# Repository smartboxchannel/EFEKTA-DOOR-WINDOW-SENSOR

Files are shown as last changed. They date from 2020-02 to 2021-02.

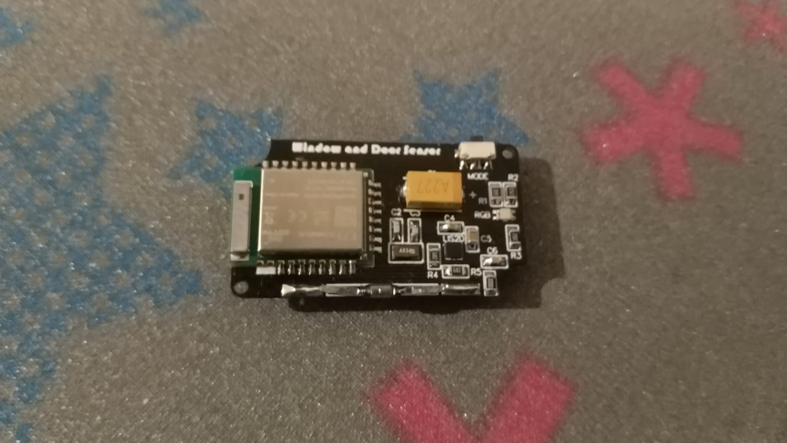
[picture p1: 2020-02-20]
IMAGES/3.jpeg

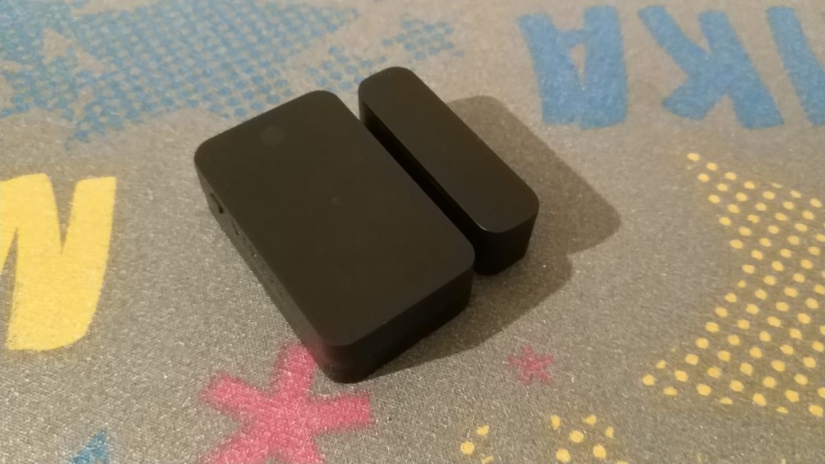
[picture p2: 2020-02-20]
IMAGES/1.jpeg

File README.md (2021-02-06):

# EFEKTA-DOOR-WINDOW-SENSOR

## Reed Switch, LIS2DW12, DRV5032FB

### (MC50SFA) nRF52811, nRF52810, nRF52832, (E73 2G4M08S1C) nRF52840

#### Don't donate to me, it doesn't work in this world: https://paypal.me/efektalab , just buy:

Video: https://youtu.be/4p1JGMze4s0

More info at http://efektalab.com/dws52 (still not working)

---

### Components (see also BOM.CSV):
#### (MC50SFA) nRF52811, nRF52810, nRF52832

1. (MC50SFA) nRF52811, nRF52810, nRF52832 (U1) - https://ali.ski/W6ErD

2. lis2dw12 (U2) - optional - https://ali.ski/h80NdJ

3. a. Reed Switch 2х14 (U3) - https://ali.ski/Uyxms

OR

3. b. Reed Switch 1.8х10 (U3) - https://ali.ski/WHlYoO

OR

3. c. Reed Switch 1.8х10 (U3) - https://ali.ski/4hPWm2

4. CR2032 Holder (U4) - https://ali.ski/9lSL8n

5. Micro Switch 2*4*3,5mm (U5,U6) - https://ali.ski/Q_WYyZ

6. DRV5032FB (U7,U8) - optional

7. RGB LED | SMD 0805 | RGBL | RGB LED - https://ali.ski/Dhf3R

8. 0603 SMD 1/8W chip resistor 3.6K (R1) - https://ali.ski/WS2ae

9. 0603 SMD 1/8W chip resistor 15K (R2) - https://ali.ski/WS2ae

10. 0603 SMD 1/8W chip resistor 10K (R3,R6) - https://ali.ski/WS2ae

11. 0603 SMD 1/8W chip resistor 5.1K (R4,R5) - https://ali.ski/WS2ae

12. 0603 SMD 1/8W chip resistor 47K (R7) - https://ali.ski/WS2ae

13. 0603 SMD 1/8W chip resistor 2M (R8) - https://ali.ski/WS2ae

14. 2x3P | 6pin | 1.27mm | SMT | Pin Header Female (J1) - https://ali.ski/Dej0c

15. Capacitor 100NF 0603 (C1, C3, C4, C6, C8) - https://ali.ski/avB9O

16. Capacitor 220UF 10V (C2) - https://ali.ski/h_HLkz

17. Capacitor 10UF 0603 (C5) - https://ali.ski/avB9O

18. Capacitor 1UF 0603 (C7) - https://ali.ski/avB9O

#### (E73_2G4M08S1C) nRF52840

1. a. nRF 52840 E73-2G4M08S1C (U1) - https://ali.ski/dFb9B

OR

1. b. nRF 52840 E73-2G4M08S1C (U1) - https://ali.ski/Qsnwk

OR

1. c. nRF 52840 E73-2G4M08S1C (U1) - https://ali.ski/dTdPtW

2. lis2dw12 (U2) - optional - https://ali.ski/h80NdJ

3. FC-135 3215 3.2*1.5 32.768KHZ Resonator (U2) - https://ali.ski/HlFD9D

4. a. Reed Switch 2х14 (U3) - https://ali.ski/Uyxms

OR

4. b. Reed Switch 1.8х10 (U3) - https://ali.ski/WHlYoO

OR

4. c. Reed Switch 1.8х10 (U3) - https://ali.ski/4hPWm2

5. CR2032 Holder (U4) - https://ali.ski/9lSL8n

6. Micro Switch 2*4*3,5mm (U5,U6) - https://ali.ski/Q_WYyZ

7. DRV5032FB (U8,U9) - optional

8. RGB LED | SMD 0805 | RGBL | RGB LED - https://ali.ski/Dhf3R

9. 0603 SMD 1/8W chip resistor 3.6K (R1) - https://ali.ski/WS2ae

10. 0603 SMD 1/8W chip resistor 15K (R2) - https://ali.ski/WS2ae

11. 0603 SMD 1/8W chip resistor 10K (R3,R6) - https://ali.ski/WS2ae

12. 0603 SMD 1/8W chip resistor 5.1K (R4,R5) - https://ali.ski/WS2ae

13. 0603 SMD 1/8W chip resistor 47K (R7) - https://ali.ski/WS2ae

14. 0603 SMD 1/8W chip resistor 2M (R8) - https://ali.ski/WS2ae

15. 2x3P | 6pin | 1.27mm | SMT | Pin Header Female (J1) - https://ali.ski/Dej0c

16. Capacitor 100NF 0603 (C1, C5, C6, C8, C10) - https://ali.ski/avB9O

17. Capacitor 220UF 10V (C2) - https://ali.ski/h_HLkz

18. Capacitor 12PF 0603 (C3, C4) - https://ali.ski/avB9O

19. Capacitor 10UF 0603 (C7) - https://ali.ski/avB9O

20. Capacitor 1UF 0603 (C9) - https://ali.ski/avB9O

---

OMO Magnetics 6х10 (2) - https://ali.ski/YDlUk2

---

M1.4 4mm Round Head Micro Screws(4) - https://ali.ski/bmMZl

---

ANYCUBIC 405nm UV resin - https://ali.ski/-PtMA-

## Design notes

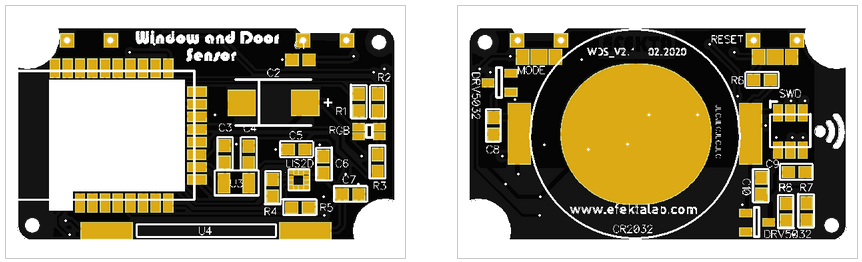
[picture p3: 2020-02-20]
IMAGES/WDS_2.1_E73 2G4M08S1C.png

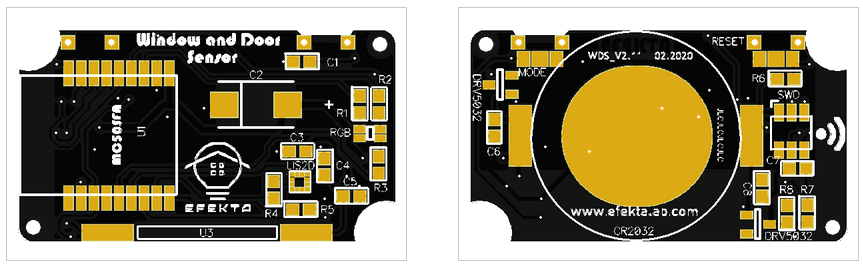
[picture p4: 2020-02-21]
IMAGES/WDS_2.11_MC50SFA.png

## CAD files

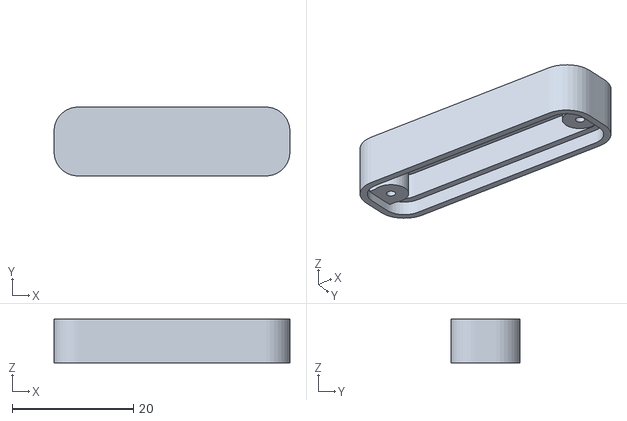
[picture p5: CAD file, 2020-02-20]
CASE/DD4.STL
39.0 x 11.4 x 7.20

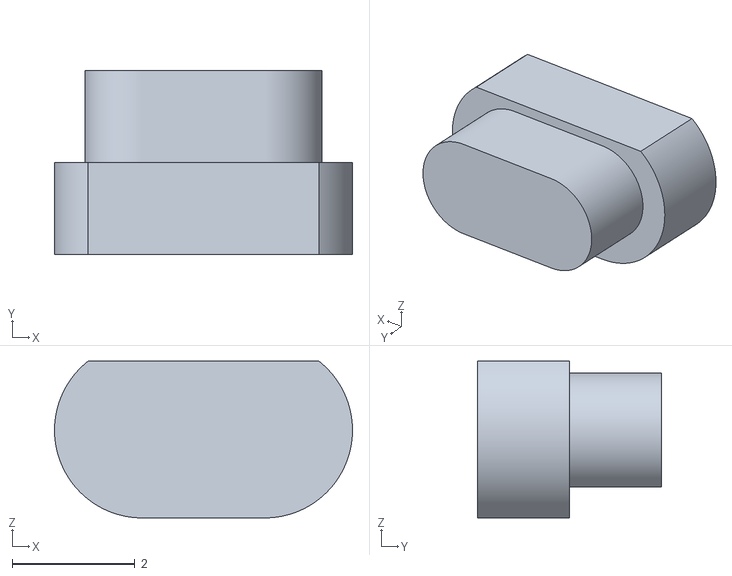
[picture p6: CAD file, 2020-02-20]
CASE/DD3.STL
4.86 x 3.00 x 2.56

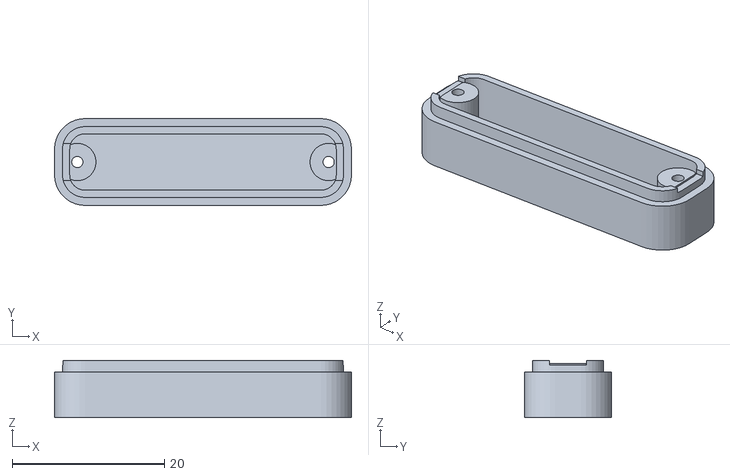
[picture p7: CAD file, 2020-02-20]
CASE/DD5.STL
39.0 x 11.4 x 7.50

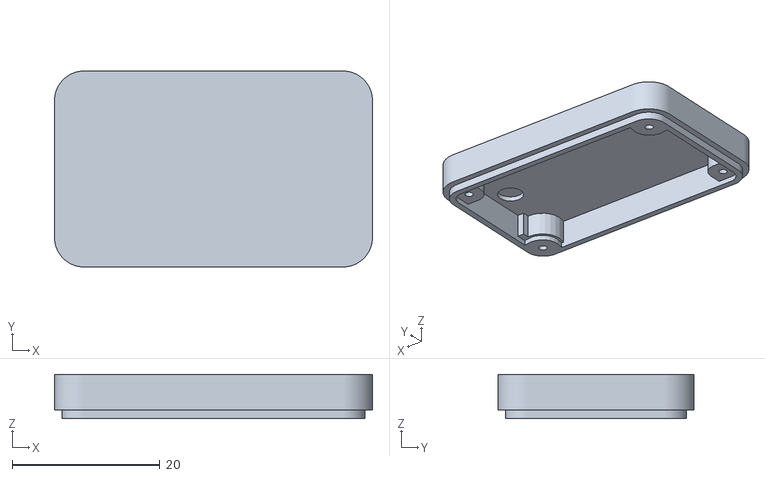
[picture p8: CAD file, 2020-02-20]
CASE/DD1.STL
43.0 x 26.5 x 6.00

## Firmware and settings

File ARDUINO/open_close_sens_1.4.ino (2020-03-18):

#define MAGNET_SENS
bool configMode;
bool door_status = true;
bool check;
#ifdef MAGNET_SENS
bool magnet_status = true;
#endif
bool vibro = true;
bool nosleep;
bool button_flag;
bool onoff = true;
bool flag_update_transport_param;
bool flag_sendRoute_parent;
bool flag_no_present;
bool flag_nogateway_mode;
bool flag_find_parent_process;
//bool flag_fcount;
bool Ack_TL;
bool Ack_FP;
bool PRESENT_ACK;
bool send_a;
bool batt_flag;
byte conf_vibro_set = 2;
byte err_delivery_beat;
byte problem_mode_count;
volatile byte axelIntStatus = 0;
volatile byte gerkIntStatus = 0;
volatile byte magIntStatus = 0;
volatile byte buttIntStatus = 0;
int8_t int_status = 0;
uint8_t  countbatt = 0;
uint8_t batt_cap;
uint8_t old_batt_cap = 100;
int16_t myid;
int16_t mypar;
int16_t old_mypar = -1;
int16_t linkQuality;
int16_t old_linkQuality;
uint16_t batteryVoltage;
uint32_t BATT_TIME;
uint32_t SLEEP_TIME = 10800000;
uint32_t SLEEP_NOGW = 60000;
uint32_t oldmillis;
uint32_t newmillis;
uint32_t previousMillis;
uint32_t lightMillisR;
uint32_t configMillis;
uint32_t interrupt_time;
uint32_t SLEEP_TIME_W;
uint32_t axel_time;
uint32_t axel_time0;
uint32_t PIN_BUTTON_MASK;
uint32_t AXEL_INT_MASK;
uint32_t GERKON_INT_MASK;
#ifdef MAGNET_SENS
uint32_t MAGNET_INT_MASK;
#endif
float ODR_1Hz6_LP_ONLY = 1.6f;
float ODR_12Hz5 = 12.5f;
float ODR_25Hz = 25.0f;
float ODR_50Hz = 50.0f;
float ODR_100Hz = 100.0f;
float ODR_200Hz = 200.0f;

//#define MY_DEBUG

#ifndef MY_DEBUG
#define MY_DISABLED_SERIAL
#endif
#define MY_RADIO_NRF5_ESB
int16_t mtwr;
#define MY_TRANSPORT_WAIT_READY_MS (mtwr)
#define MY_NRF5_ESB_PA_LEVEL (NRF5_PA_LOW)

#include <LIS2DW12Sensor.h>
LIS2DW12Sensor *lis2;

#include <MySensors.h>

extern "C" {
#include "app_gpiote.h"
#include "nrf_gpio.h"
}
#define APP_GPIOTE_MAX_USERS 1
static app_gpiote_user_id_t m_gpiote_user_id;

#define DWS_CHILD_ID 0
#define V_SENS_CHILD_ID 1
#ifdef MAGNET_SENS
#define M_CHILD_ID 2
#endif
#define LEVEL_SENSIV_V_SENS_CHILD_ID 230
#define SIGNAL_Q_ID 250

MyMessage dwsMsg(DWS_CHILD_ID, V_TRIPPED);
#ifdef MAGNET_SENS
MyMessage mMsg(M_CHILD_ID, V_TRIPPED);
#endif
MyMessage vibroMsg(V_SENS_CHILD_ID, V_TRIPPED);
MyMessage conf_vsensMsg(LEVEL_SENSIV_V_SENS_CHILD_ID, V_VAR1);
#define SN "DOOR & WINDOW SENS"
#define SV "1.14"


void before() {
  board_Init();
  happy_init();
  delay(500);
  batteryVoltage = hwCPUVoltage();
  digitalWrite(BLUE_LED, LOW);
}


void presentation()
{
  check = sendSketchInfo(SN, SV);
  if (!check) {
    _transportSM.failedUplinkTransmissions = 0;
    wait(10);
    check = sendSketchInfo(SN, SV);
    wait(10);
    _transportSM.failedUplinkTransmissions = 0;
  }
  if (check) {
    blinky(1, 1, BLUE_LED);
  } else {
    blinky(1, 1, RED_LED);
  }

  check = present(DWS_CHILD_ID, S_DOOR, "STATUS RS SENS");
  if (!check) {
    _transportSM.failedUplinkTransmissions = 0;
    wait(20);
    check = present(DWS_CHILD_ID, S_DOOR, "STATUS RS SENS");
    wait(20);
    _transportSM.failedUplinkTransmissions = 0;
  }
  if (check) {
    blinky(1, 1, BLUE_LED);
  } else {
    blinky(1, 1, RED_LED);
  }

  check = present(V_SENS_CHILD_ID, S_VIBRATION, "STATUS SHOCK SENS");
  if (!check) {
    _transportSM.failedUplinkTransmissions = 0;
    wait(30);
    check = present(V_SENS_CHILD_ID, S_VIBRATION, "STATUS SHOCK SENS");
    wait(30);
    _transportSM.failedUplinkTransmissions = 0;
  }
  if (check) {
    blinky(1, 1, BLUE_LED);
  } else {
    blinky(1, 1, RED_LED);
  }
#ifdef MAGNET_SENS
  check = present(M_CHILD_ID, S_DOOR, "ANTI-MAGNET ALARM");
  if (!check) {
    _transportSM.failedUplinkTransmissions = 0;
    wait(40);
    check = present(M_CHILD_ID, S_DOOR, "ANTI-MAGNET ALARM");
    wait(40);
    _transportSM.failedUplinkTransmissions = 0;
  }
  if (check) {
    blinky(1, 1, BLUE_LED);
  } else {
    blinky(1, 1, RED_LED);
  }
#endif
  check = present(SIGNAL_Q_ID, S_CUSTOM, "SIGNAL %");
  if (!check) {
    _transportSM.failedUplinkTransmissions = 0;
    wait(40);
    check = present(SIGNAL_Q_ID, S_CUSTOM, "SIGNAL %");
    wait(40);
    _transportSM.failedUplinkTransmissions = 0;
  }
  if (check) {
    blinky(1, 1, BLUE_LED);
  } else {
    blinky(1, 1, RED_LED);
  }

  check = present(LEVEL_SENSIV_V_SENS_CHILD_ID, S_CUSTOM, "SENS LEVEL VIBRO");
  if (!check) {
    _transportSM.failedUplinkTransmissions = 0;
    wait(50);
    check = present(LEVEL_SENSIV_V_SENS_CHILD_ID, S_CUSTOM, "SENS LEVEL VIBRO");
    wait(50);
    _transportSM.failedUplinkTransmissions = 0;
  }
  if (check) {
    blinky(1, 1, BLUE_LED);
  } else {
    blinky(1, 1, RED_LED);
  }

  check = send(conf_vsensMsg.set(conf_vibro_set));
  if (!check) {
    _transportSM.failedUplinkTransmissions = 0;
    wait(60);
    check = send(conf_vsensMsg.set(conf_vibro_set));
    wait(60);
    _transportSM.failedUplinkTransmissions = 0;
  }
  if (check) {
    blinky(1, 1, BLUE_LED);
  } else {
    blinky(1, 1, RED_LED);
  }
}


void setup() {
  digitalWrite(BLUE_LED, HIGH);
  config_Happy_node();
  sensors_Init();
}


void loop() {
  if (flag_update_transport_param == true) {
    update_Happy_transport();
  }
  if (flag_sendRoute_parent == true) {
    present_only_parent();
  }
  if (isTransportReady() == true) {
    if (flag_nogateway_mode == false) {
      if (flag_find_parent_process == true) {
        find_parent_process();
      }
      if (configMode == false) {
#ifdef MAGNET_SENS
        if ((axelIntStatus == AXEL_INT) || (buttIntStatus == PIN_BUTTON) || (gerkIntStatus == GERKON_INT) || (magIntStatus == MAGNET_INT)) {
#else
        if ((axelIntStatus == AXEL_INT) || (buttIntStatus == PIN_BUTTON) || (gerkIntStatus == GERKON_INT)) {
#endif
          nosleep = true;
          newmillis = millis();
          interrupt_time = newmillis - oldmillis;
          BATT_TIME = BATT_TIME - interrupt_time;
          if (BATT_TIME < 60000) {
            BATT_TIME = SLEEP_TIME;
            batteryVoltage = hwCPUVoltage();
            batt_flag = true;
          }

          if (gerkIntStatus == GERKON_INT) {
            send_Gerkon();
            axel_time = millis();
            nosleep = false;
          }
#ifdef MAGNET_SENS
          if (magIntStatus == MAGNET_INT) {
            send_Magnet();
            nosleep = false;
          }
#endif
          if (axelIntStatus == AXEL_INT) {
            if (millis() - axel_time0 >= 2000) {
              send_Axel();
              nosleep = false;
            } else {
              if (digitalRead(GERKON_INT) == LOW) {
                send_Gerkon();
                axel_time = millis();
                nosleep = false;
              }
            }
          }

          if (buttIntStatus == PIN_BUTTON) {
            if (digitalRead(PIN_BUTTON) == LOW && button_flag == false) {
              button_flag = true;
              previousMillis = millis();
              ledsOff();
            }
            if (digitalRead(PIN_BUTTON) == LOW && button_flag == true) {
              if ((millis() - previousMillis > 0) && (millis() - previousMillis <= 1750)) {
                if (millis() - lightMillisR > 70) {
                  lightMillisR = millis();
                  onoff = !onoff;
                  digitalWrite(BLUE_LED, onoff);
                }
              }
              if ((millis() - previousMillis > 1750) && (millis() - previousMillis <= 2000)) {
                ledsOff();
              }
              if ((millis() - previousMillis > 2000) && (millis() - previousMillis <= 3750)) {
                if (millis() - lightMillisR > 50) {
                  lightMillisR = millis();
                  onoff = !onoff;
                  digitalWrite(GREEN_LED, onoff);
                }
              }
              if ((millis() - previousMillis > 3750) && (millis() - previousMillis <= 4000)) {
                ledsOff();
              }
              if ((millis() - previousMillis > 4000) && (millis() - previousMillis <= 5750)) {
                if (millis() - lightMillisR > 30) {
                  lightMillisR = millis();
                  onoff = !onoff;
                  digitalWrite(RED_LED, onoff);
                }
              }
              if (millis() - previousMillis > 5750) {
                ledsOff();
              }
            }

            if (digitalRead(PIN_BUTTON) == HIGH && button_flag == true) {
              if ((millis() - previousMillis <= 1750) && (button_flag == true))
              {
                ledsOff();
                blinky(2, 2, BLUE_LED);
                button_flag = false;
                buttIntStatus = 0;
                presentation();
                nosleep = false;
              }
              if ((millis() - previousMillis > 2000) && (millis() - previousMillis <= 3750) && (button_flag == true))
              {
                ledsOff();
                blinky(2, 2, GREEN_LED);
                configMode = true;
                button_flag = false;
                configMillis = millis();
                interrupt_Init(true);
                buttIntStatus = 0;
                NRF5_ESB_startListening();
                wait(50);
              }

              if ((millis() - previousMillis > 4000) && (millis() - previousMillis <= 5750) && (button_flag == true))
              {
                ledsOff();
                blinky(3, 3, RED_LED);
                new_device();
              }

              if ((((millis() - previousMillis > 1750) && (millis() - previousMillis <= 2000)) || ((millis() - previousMillis > 3750) && (millis() - previousMillis <= 4000)) || ((millis() - previousMillis > 5750))) && (button_flag == true))
              {
                ledsOff();
                nosleep = false;
                button_flag = false;
                buttIntStatus = 0;
              }
            }
          }
        } else {
          batteryVoltage = hwCPUVoltage();
          BATT_TIME = SLEEP_TIME;
          sendBatteryStatus(true);
          nosleep = false;
        }
      } else {
        if (millis() - configMillis > 30000) {
          blinky(3, 3, GREEN_LED);
          configMode = false;
          nosleep = false;
          interrupt_Init(false);
          wait(50);
        }
      }
    } else {
      if (buttIntStatus == PIN_BUTTON) {
        if (digitalRead(PIN_BUTTON) == LOW && button_flag == false) {
          button_flag = true;
          nosleep = true;
          previousMillis = millis();
          ledsOff();
        }
        if (digitalRead(PIN_BUTTON) == LOW && button_flag == true) {
          if ((millis() - previousMillis > 0) && (millis() - previousMillis <= 1750)) {
            if (millis() - lightMillisR > 25) {
              lightMillisR = millis();
              onoff = !onoff;
              digitalWrite(GREEN_LED, onoff);
            }
          }
          if ((millis() - previousMillis > 1750) && (millis() - previousMillis <= 2000)) {
            ledsOff();
          }
          if ((millis() - previousMillis > 2000) && (millis() - previousMillis <= 4000)) {
            if (millis() - lightMillisR > 25) {
              lightMillisR = millis();
              onoff = !onoff;
              digitalWrite(RED_LED, onoff);
            }
          }
          if (millis() - previousMillis > 4000) {
            ledsOff();
          }
        }

        if (digitalRead(PIN_BUTTON) == HIGH && button_flag == true) {
          if ((millis() - previousMillis <= 1750) && (button_flag == true))
          {
            ledsOff();
            blinky(2, 2, BLUE_LED);
            button_flag = false;
            buttIntStatus = 0;
            check_parent();
            nosleep = false;
          }
          if ((millis() - previousMillis > 2000) && (millis() - previousMillis <= 4000) && (button_flag == true))
          {
            ledsOff();
            blinky(3, 3, RED_LED);
            new_device();
          }

          if ((((millis() - previousMillis > 1750) && (millis() - previousMillis <= 2000)) || ((millis() - previousMillis > 4000))) && (button_flag == true))
          {
            ledsOff();
            nosleep = false;
            button_flag = false;
            buttIntStatus = 0;
          }
        }
      } else {
        check_parent();
      }
    }
  }

  if (_transportSM.failureCounter > 0)
  {
    _transportConfig.parentNodeId = loadState(101);
    _transportConfig.nodeId = myid;
    _transportConfig.distanceGW = loadState(103);
    mypar = _transportConfig.parentNodeId;
    nosleep = false;
    //flag_fcount = 1;
    err_delivery_beat = 6;
    happy_node_mode();
    gateway_fail();
  }

  if (nosleep == false) {
    oldmillis = millis();
    axelIntStatus = 0;
    buttIntStatus = 0;
    gerkIntStatus = 0;
#ifdef MAGNET_SENS
    magIntStatus = 0;
#endif
    sleep(SLEEP_TIME_W, false);
    nosleep = true;
  }
}


void blinky(uint8_t pulses, uint8_t repit, uint8_t ledColor) {
  for (int x = 0; x < repit; x++) {
    if (x > 0) {
      sleep(100);
    }
    for (int i = 0; i < pulses; i++) {
      if (i > 0) {
        sleep(40);
      }
      digitalWrite(ledColor, LOW);
      sleep(10);
      digitalWrite(ledColor, HIGH);
    }
  }
}


void board_Init() {
  pinMode(PIN_BUTTON, INPUT_PULLUP);
#ifdef MAGNET_SENS
  pinMode(MAGNET_INT, INPUT);
#endif
  pinMode(GERKON_INT, INPUT);
  pinMode(AXEL_INT, INPUT);
  pinMode(RED_LED, OUTPUT);
  pinMode(GREEN_LED, OUTPUT);
  pinMode(BLUE_LED, OUTPUT);
  ledsOff();
  NRF_POWER->DCDCEN = 1;
  wait(5);
#ifndef MY_DEBUG
  NRF_UART0->ENABLE = 0;
  wait(5);
#endif
  NRF_NFCT->TASKS_DISABLE = 1;
  NRF_NVMC->CONFIG = 1;
  NRF_UICR->NFCPINS = 0;
  NRF_NVMC->CONFIG = 0;
  NRF_SAADC ->ENABLE = 0;
  NRF_PWM0  ->ENABLE = 0;
  NRF_PWM1  ->ENABLE = 0;
  NRF_PWM2  ->ENABLE = 0;
  NRF_TWIM1 ->ENABLE = 0;
  NRF_TWIS1 ->ENABLE = 0;
  //NRF_RADIO->TXPOWER = 8;
  wait(5);

  conf_vibro_set = loadState(230);
  if ((conf_vibro_set > 5) || (conf_vibro_set == 0)) {
    conf_vibro_set = 2;
    saveState(230, conf_vibro_set);
  }

  blinky(1, 1, GREEN_LED);
}


void ledsOff() {
  digitalWrite(RED_LED, HIGH);
  digitalWrite(GREEN_LED, HIGH);
  digitalWrite(BLUE_LED, HIGH);
}


void happy_init() {
  //hwWriteConfig(EEPROM_NODE_ID_ADDRESS, 255); // ******************** checking the node config reset *************************

  if (hwReadConfig(EEPROM_NODE_ID_ADDRESS) == 0) {
    hwWriteConfig(EEPROM_NODE_ID_ADDRESS, 255);
  }
  if (loadState(100) == 0) {
    saveState(100, 255);
  }
  CORE_DEBUG(PSTR("EEPROM NODE ID: %d\n"), hwReadConfig(EEPROM_NODE_ID_ADDRESS));
  CORE_DEBUG(PSTR("USER MEMORY SECTOR NODE ID: %d\n"), loadState(100));

  if (hwReadConfig(EEPROM_NODE_ID_ADDRESS) == 255) {
    mtwr = 0;
  } else {
    mtwr = 6000;
    no_present();
  }
  CORE_DEBUG(PSTR("MY_TRANSPORT_WAIT_MS: %d\n"), mtwr);
}

void no_present() {
  _coreConfig.presentationSent = true;
  _coreConfig.nodeRegistered = true;
}


void interrupt_Init(bool start) {
  //***
  //NRF_GPIO_PIN_NOPULL
  //NRF_GPIO_PIN_PULLUP
  //NRF_GPIO_PIN_PULLDOWN
  //***
  nrf_gpio_cfg_input(PIN_BUTTON, NRF_GPIO_PIN_PULLUP);
  nrf_gpio_cfg_input(AXEL_INT, NRF_GPIO_PIN_NOPULL);
  nrf_gpio_cfg_input(GERKON_INT, NRF_GPIO_PIN_NOPULL);
#ifdef MAGNET_SENS
  nrf_gpio_cfg_input(MAGNET_INT, NRF_GPIO_PIN_NOPULL);
#endif
  APP_GPIOTE_INIT(APP_GPIOTE_MAX_USERS);
  PIN_BUTTON_MASK = 1 << PIN_BUTTON;
  AXEL_INT_MASK = 1 << AXEL_INT;
  GERKON_INT_MASK = 1 << GERKON_INT;
#ifdef MAGNET_SENS
  MAGNET_INT_MASK = 1 << MAGNET_INT;
#endif
  if (start == false) {

#ifdef MAGNET_SENS
    app_gpiote_user_register(&m_gpiote_user_id, AXEL_INT_MASK | GERKON_INT_MASK, GERKON_INT_MASK | MAGNET_INT_MASK | PIN_BUTTON_MASK, gpiote_event_handler);
#else
    app_gpiote_user_register(&m_gpiote_user_id, AXEL_INT_MASK | GERKON_INT_MASK, GERKON_INT_MASK | PIN_BUTTON_MASK, gpiote_event_handler);
#endif
    wait(5);
  } else if (start == true) {
#ifdef MAGNET_SENS
    app_gpiote_user_register(&m_gpiote_user_id, GERKON_INT_MASK, GERKON_INT_MASK | MAGNET_INT_MASK | PIN_BUTTON_MASK, gpiote_event_handler);
#else
    app_gpiote_user_register(&m_gpiote_user_id, GERKON_INT_MASK, GERKON_INT_MASK | PIN_BUTTON_MASK, gpiote_event_handler);
#endif
    wait(5);
  }
  app_gpiote_user_enable(m_gpiote_user_id);
  wait(5);
  axelIntStatus = 0;
  buttIntStatus = 0;
  gerkIntStatus = 0;
#ifdef MAGNET_SENS
  magIntStatus = 0;
#endif
}


void gpiote_event_handler(uint32_t event_pins_low_to_high, uint32_t event_pins_high_to_low)
{
  MY_HW_RTC->CC[0] = (MY_HW_RTC->COUNTER + 2); // Taken from d0016 example code, ends the sleep delay

  if (PIN_BUTTON_MASK & event_pins_high_to_low) {
#ifdef MAGNET_SENS
    if ((buttIntStatus == 0) && (axelIntStatus == 0) && (gerkIntStatus == 0) && (magIntStatus == 0)) {
#else
    if ((buttIntStatus == 0) && (axelIntStatus == 0) && (gerkIntStatus == 0)) {
#endif
      buttIntStatus = PIN_BUTTON;
    }
  }
  if (flag_nogateway_mode == false) {
    if (AXEL_INT_MASK & event_pins_low_to_high) {
#ifdef MAGNET_SENS
      if ((axelIntStatus == 0) && (buttIntStatus == 0) && (gerkIntStatus == 0) && (magIntStatus == 0) && (door_status == 1)) {
#else
      if ((axelIntStatus == 0) && (buttIntStatus == 0) && (gerkIntStatus == 0) && (door_status == 1)) {
#endif
        axelIntStatus = AXEL_INT;
        axel_time0 = millis();
      }
    }
    if ((GERKON_INT_MASK & event_pins_low_to_high) || (GERKON_INT_MASK & event_pins_high_to_low)) {
#ifdef MAGNET_SENS
      if ((axelIntStatus == 0) && (buttIntStatus == 0) && (gerkIntStatus == 0) && (magIntStatus == 0)) {
#else
      if ((axelIntStatus == 0) && (buttIntStatus == 0) && (gerkIntStatus == 0)) {
#endif
        gerkIntStatus = GERKON_INT;
      }
    }
#ifdef MAGNET_SENS
    if (MAGNET_INT_MASK & event_pins_high_to_low) {
      if ((axelIntStatus == 0) && (buttIntStatus == 0) && (gerkIntStatus == 0) && (magIntStatus == 0) && (door_status == 1)) {
        magIntStatus = MAGNET_INT;
      }
    }
#endif
  }
}


void sensors_Init() {
  Wire.begin();
  wait(200);
  lis2 = new LIS2DW12Sensor (&Wire);
  vibro_Init();
  if (flag_nogateway_mode == false) {
    if (digitalRead(GERKON_INT) == HIGH) {
      door_status = true;
      interrupt_Init(false);
    } else {
      door_status = false;
      interrupt_Init(true);
    }
    send(dwsMsg.set(door_status));
    SLEEP_TIME_W = SLEEP_TIME;
    axelIntStatus = 0;
    buttIntStatus = 0;
    gerkIntStatus = 0;
#ifdef MAGNET_SENS
    magIntStatus = 0;
#endif
    sendBatteryStatus(false);
    blinky(2, 1, BLUE_LED);
    wait(100);
    blinky(2, 1, GREEN_LED);
    axel_time = millis();
  } else {
    interrupt_Init(true);
    blinky(5, 3, RED_LED);
  }
}


void config_Happy_node() {
  if (mtwr == 0) {
    myid = getNodeId();
    saveState(100, myid);
    mypar = _transportConfig.parentNodeId;
    old_mypar = mypar;
    saveState(101, mypar);
    saveState(102, _transportConfig.distanceGW);
  }
  if (mtwr != 0) {
    myid = getNodeId();
    if (myid != loadState(100)) {
      saveState(100, myid);
    }
    if (isTransportReady() == true) {
      mypar = _transportConfig.parentNodeId;
      if (mypar != loadState(101)) {
        saveState(101, mypar);
      }
      if (_transportConfig.distanceGW != loadState(102)) {
        saveState(102, _transportConfig.distanceGW);
      }
      present_only_parent();
    }
    if (isTransportReady() == false)
    {
      no_present();
      err_delivery_beat = 6;
      _transportConfig.nodeId = myid;
      _transportConfig.parentNodeId = loadState(101);
      _transportConfig.distanceGW = loadState(102);
      mypar = _transportConfig.parentNodeId;
      happy_node_mode();
      gateway_fail();
    }
  }
}


void send_Axel() {
  if (millis() - axel_time >= 5000) {
    blinky(1, 1, BLUE_LED);
    blinky(1, 1, RED_LED);
    blinky(1, 1, BLUE_LED);
    blinky(1, 1, RED_LED);

    send_a = send(vibroMsg.set(vibro));
    if (send_a == false) {
      wait(30);
      send_a = send(vibroMsg.set(vibro));
    }
    if (send_a == true) {
      err_delivery_beat = 0;
      if (flag_nogateway_mode == true) {
        flag_nogateway_mode = false;
        CORE_DEBUG(PSTR("MyS: NORMAL GATEWAY MODE\n"));
        err_delivery_beat = 0;
      }
    } else {
      _transportSM.failedUplinkTransmissions = 0;
      if (err_delivery_beat < 6) {
        err_delivery_beat++;
      }
      if (err_delivery_beat == 5) {
        if (flag_nogateway_mode == 0) {
          gateway_fail();
          CORE_DEBUG(PSTR("MyS: LOST GATEWAY MODE\n"));
        }
      }
    }
    axel_time = millis();
    axelIntStatus = 0;
    nosleep = false;
  } else {
    axelIntStatus = 0;
    nosleep = false;
  }
}


void send_Gerkon() {
  if (digitalRead(GERKON_INT) == HIGH) {
    door_status = true;
    interrupt_Init(false);
  } else {
    door_status = false;
    interrupt_Init(true);
  }
  if (door_status == true) {
    blinky(1, 1, GREEN_LED);
  } else {
    blinky(1, 1, RED_LED);
  }
  send_a = send(dwsMsg.set(door_status));
  if (send_a == false) {
    wait(20);
    send_a = send(dwsMsg.set(door_status));
    if (send_a == false) {
      wait(40);
      send_a = send(dwsMsg.set(door_status));
    }
  }
  if (send_a == true) {
    err_delivery_beat = 0;
    if (flag_nogateway_mode == true) {
      flag_nogateway_mode = false;
      CORE_DEBUG(PSTR("MyS: NORMAL GATEWAY MODE\n"));
      err_delivery_beat = 0;
    }
  } else {
    _transportSM.failedUplinkTransmissions = 0;
    if (err_delivery_beat < 6) {
      err_delivery_beat++;
    }
    if (err_delivery_beat == 5) {
      if (flag_nogateway_mode == false) {
        gateway_fail();
        CORE_DEBUG(PSTR("MyS: LOST GATEWAY MODE\n"));
      }
    }
  }
  gerkIntStatus = 0;
  nosleep = false;
}
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

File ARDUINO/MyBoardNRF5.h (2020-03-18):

/*
  If you don't use an nRF5 board, you can ignore this file.

  This file was part of the "My Sensors nRF5 Boards" board repository
  available at https://github.com/mysensors/ArduinoBoards If you have
  questions, please refer the documentation at
  https://github.com/mysensors/ArduinoHwNRF5 first.

  This file is compatible with ArduinoHwNRF5 >= 0.2.0

  This file allows you to change the pins of internal hardware, like the
  serial port, SPI bus or Wire bus.

  All pins referenced here are mapped via the "g_ADigitalPinMap" Array
  defined in "MyBoardNRF5.cpp" to pins of the MCU.
  
  As an example, if you have at the third position in "g_ADigitalPinMap" the
  12, then all ports referenced in Arduino with 2 are mapped to P0.12. If you
  don't change the "g_ADigitalPinMap" Array, the Arduino pins 0..31 are
  translated to P0.00..P0..31.
   
  ###########################################################################
 
  This file is compatible with ArduinoHwNRF5 > 0.1.0
  Copyright (c) 2014-2015 Arduino LLC.  All right reserved.
  Copyright (c) 2016 Sandeep Mistry. All right reserved.
  Copyright (c) 2017 Sensnology AB. All right reserved.

  This library is free software; you can redistribute it and/or
  modify it under the terms of the GNU Lesser General Public
  License as published by the Free Software Foundation; either
  version 2.1 of the License, or (at your option) any later version.
  This library is distributed in the hope that it will be useful,
  but WITHOUT ANY WARRANTY; without even the implied warranty of
  MERCHANTABILITY or FITNESS FOR A PARTICULAR PURPOSE.
  See the GNU Lesser General Public License for more details.
  You should have received a copy of the GNU Lesser General Public
  License along with this library; if not, write to the Free Software
  Foundation, Inc., 51 Franklin St, Fifth Floor, Boston, MA  02110-1301  USA
*/

#ifndef _MYBOARDNRF5_H_
#define _MYBOARDNRF5_H_

#ifdef __cplusplus
extern "C"
{
#endif // __cplusplus

// Number of pins defined in PinDescription array
#if defined(NRF52840)
#define GPIO_COUNT 2
#define PINS_COUNT           (48u)
#define NUM_DIGITAL_PINS     (48u)
#define NUM_ANALOG_INPUTS    (8u)
#define NUM_ANALOG_OUTPUTS   (8u)
#else
#define GPIO_COUNT 2
#define PINS_COUNT           (32u)
#define NUM_DIGITAL_PINS     (32u)
#define NUM_ANALOG_INPUTS    (8u)
#define NUM_ANALOG_OUTPUTS   (8u)
#endif

/* 
 *  LEDs
 *  
 *  This is optional
 *  
 *  With My Sensors, you can use
 *  hwPinMode() instead of pinMode()
 *  hwPinMode() allows to use advanced modes like OUTPUT_H0H1 to drive LEDs.
 *  https://github.com/mysensors/MySensors/blob/development/drivers/NRF5/nrf5_wiring_constants.h
 *
 */
#define PIN_LED1                (13)
#define PIN_LED2                (24)
#define PIN_LED3                (5)
// #define PIN_LED4                (27)
// #define PIN_LED5                (12)
// #define PIN_LED6                (14)
// #define PIN_LED7                (15)
// #define PIN_LED8                (16)
// #define USER_LED             	 (PIN_LED2)
#define RED_LED                (PIN_LED1)
#define GREEN_LED            	 (PIN_LED2)
#define BLUE_LED			         (PIN_LED3)
// #define BLE_LED                 BLUE_LED
// #define LED_BUILTIN          PIN_LED1

/* 
 *  Buttons
 *  
 *  This is optional
 */
#define PIN_BUTTON            (2)
// #define PIN_BUTTON2             (4)
// #define PIN_BUTTON3             (5)
// #define PIN_BUTTON4             (6)
// #define PIN_BUTTON5             (7)
// #define PIN_BUTTON6             (8)
// #define PIN_BUTTON7             (9)
// #define PIN_BUTTON8             (10)

#define AXEL_INT             (29)
#define MAGNET_INT             (28)
#define GERKON_INT             (3)

/* 
 * Analog ports
 *  
 * If you change g_APinDescription, replace PIN_AIN0 with
 * port numbers mapped by the g_APinDescription Array.
 * You can add PIN_AIN0 to the g_APinDescription Array if
 * you want provide analog ports MCU independed, you can add
 * PIN_AIN0..PIN_AIN7 to your custom g_APinDescription Array
 * defined in MyBoardNRF5.cpp
 */
static const uint8_t A0  = ADC_A0;
static const uint8_t A1  = ADC_A1;
static const uint8_t A2  = ADC_A2;
static const uint8_t A3  = ADC_A3;
static const uint8_t A4  = ADC_A4;
static const uint8_t A5  = ADC_A5;
static const uint8_t A6  = ADC_A6;
static const uint8_t A7  = ADC_A7;

/*
 * Serial interfaces
 * 
 * RX and TX are required.
 * If you have no serial port, use unused pins
 * CTS and RTS are optional.
 */
#define PIN_SERIAL_RX       (9)
#define PIN_SERIAL_TX       (10)
// #define PIN_SERIAL_CTS      (13)
// #define PIN_SERIAL_RTS      (14)

/*
 * SPI Interfaces
 * 
 * This is optional
 * 
 * If SPI is defined MISO, MOSI, SCK are required
 * SS is optional and can be used in your sketch.
 */
#define SPI_INTERFACES_COUNT 1

#define PIN_SPI_MISO         (15)
#define PIN_SPI_MOSI         (17)
#define PIN_SPI_SCK          (20)
#define PIN_SPI_SS           (22)
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
